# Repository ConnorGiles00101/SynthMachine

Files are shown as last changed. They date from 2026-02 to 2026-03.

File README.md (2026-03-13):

# SynthMachine
A set of Modular synthesizer modules designed around the SSI2130 VCO, SSI2140 Multi-Mode Filter, and the Daisy Seed Microcontroller.

Firmware requires a daisy seed build environment to compile, see daisy seed startup guide (https://daisy.audio/tutorials/cpp-dev-env/), requires updated libdaisy, daisysp, etc... to be cloned from relevant repos.

Very much a prototype.

Credit to timMJN and his Polymorph VCO module: https://github.com/TimMJN/Polymorph-VCO
His designs were helpful reference whilst learning modular synth i/o and standards regarding audio and CV voltage ranges and impedance.

VCO Machine and VCF Machine are designed to use the DAB2130 and DAB2140 breakout boards. As such they have DIP footprints instead of QFN, and do not have decoupling capacitors as they are already included on the breakout.

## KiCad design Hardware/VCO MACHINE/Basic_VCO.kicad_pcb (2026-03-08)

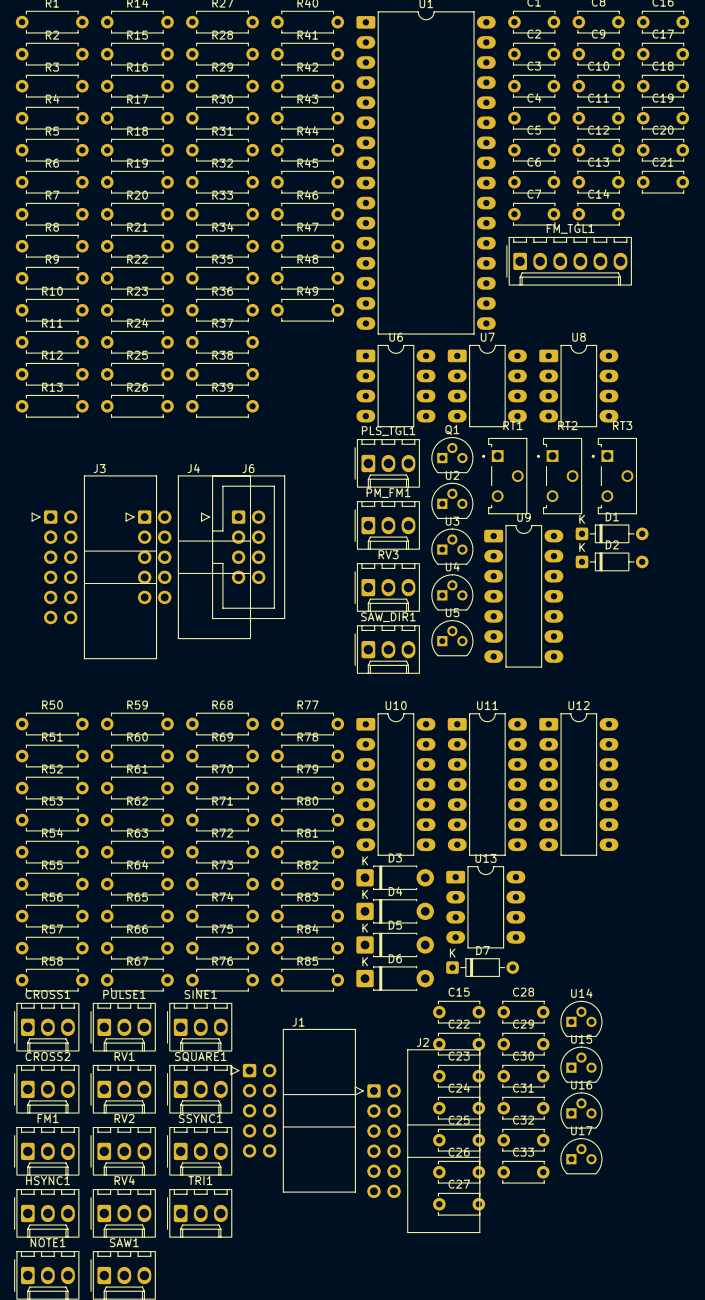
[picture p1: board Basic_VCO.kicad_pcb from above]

Board: 4 copper layers, 170 parts (0 on the bottom side), 105 nets, no tracks yet.

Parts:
C1, C3, C30, C31: 0.33uF; C_Disc_D5.0mm_W2.5mm_P5.00mm
C2, C4, C12, C14, C16, C17, C18, C19, C20, C21, C22, C23, C24, C25, C26, C27, C28, C29, C32, C33: 0.1uF; C_Disc_D5.0mm_W2.5mm_P5.00mm
C5, C6, C8: 10nF; C_Disc_D5.0mm_W2.5mm_P5.00mm
C7: 3.9nF; C_Disc_D5.0mm_W2.5mm_P5.00mm
C9: 10uF; C_Disc_D5.0mm_W2.5mm_P5.00mm
C10, C11, C13, C15: 100pF; C_Disc_D5.0mm_W2.5mm_P5.00mm
CROSS1, CROSS2: AudioJack2_SwitchT; Molex_KK-254_AE-6410-03A_1x03_P2.54mm_Vertical
D1, D2, D7: 1N4148; D_DO-35_SOD27_P7.62mm_Horizontal
D3, D4, D5, D6: 1N5817; D_DO-41_SOD81_P7.62mm_Horizontal
FM1: AudioJack2_SwitchT; Molex_KK-254_AE-6410-03A_1x03_P2.54mm_Vertical
FM_TGL1: SW_DPDT_x2; Molex_KK-254_AE-6410-06A_1x06_P2.54mm_Vertical
HSYNC1: AudioJack2_SwitchT; Molex_KK-254_AE-6410-03A_1x03_P2.54mm_Vertical
J1, J4: Conn_02x05_Odd_Even; IDC-Header_2x05_P2.54mm_Horizontal
J2, J3: Conn_02x06_Odd_Even; IDC-Header_2x06_P2.54mm_Horizontal
J6: Conn_02x05_Odd_Even; IDC-Header_2x04_P2.54mm_Vertical
NOTE1: AudioJack2_SwitchT; Molex_KK-254_AE-6410-03A_1x03_P2.54mm_Vertical
PLS_TGL1: SW_SPDT; Molex_KK-254_AE-6410-03A_1x03_P2.54mm_Vertical
PM_FM1: SW_SPDT; Molex_KK-254_AE-6410-03A_1x03_P2.54mm_Vertical
PULSE1: AudioJack2_SwitchT; Molex_KK-254_AE-6410-03A_1x03_P2.54mm_Vertical
Q1: 2N7000; TO-92
R1, R3, R58, R83: 10; R_Axial_DIN0207_L6.3mm_D2.5mm_P7.62mm_Horizontal
R2, R4, R13, R84, R85: 267; R_Axial_DIN0207_L6.3mm_D2.5mm_P7.62mm_Horizontal
R5: 15k; R_Axial_DIN0207_L6.3mm_D2.5mm_P7.62mm_Horizontal
R6, R7, R10, R15, R26, R35, R37, R45, R47, R57, R59, R63, R67, R71, R75: 10k; R_Axial_DIN0207_L6.3mm_D2.5mm_P7.62mm_Horizontal
R8, R50, R51, R52, R53, R54, R55, R81, R82: 49.9k; R_Axial_DIN0207_L6.3mm_D2.5mm_P7.62mm_Horizontal
R9: 267k; R_Axial_DIN0207_L6.3mm_D2.5mm_P7.62mm_Horizontal
R11, R24, R25, R34: 100k; R_Axial_DIN0207_L6.3mm_D2.5mm_P7.62mm_Horizontal
R12: 22.1k; R_Axial_DIN0207_L6.3mm_D2.5mm_P7.62mm_Horizontal
R14, R16, R33: 100; R_Axial_DIN0207_L6.3mm_D2.5mm_P7.62mm_Horizontal
R17: 19.6k; R_Axial_DIN0207_L6.3mm_D2.5mm_P7.62mm_Horizontal
R18, R20: 4.75k; R_Axial_DIN0207_L6.3mm_D2.5mm_P7.62mm_Horizontal
R19: 4.02k; R_Axial_DIN0207_L6.3mm_D2.5mm_P7.62mm_Horizontal
R21: 12.7k; R_Axial_DIN0207_L6.3mm_D2.5mm_P7.62mm_Horizontal
R22, R23, R27, R28, R29, R30, R31, R32, R38, R39, R40, R41, R42, R43, R44, R46, R48, R49, R60, R64, R68, R72, R76, R78: 20k; R_Axial_DIN0207_L6.3mm_D2.5mm_P7.62mm_Horizontal
R36: 499k; R_Axial_DIN0207_L6.3mm_D2.5mm_P7.62mm_Horizontal
R56: 90.9k; R_Axial_DIN0207_L6.3mm_D2.5mm_P7.62mm_Horizontal
R61, R65, R69, R73: 40.2k; R_Axial_DIN0207_L6.3mm_D2.5mm_P7.62mm_Horizontal
R62, R66, R70, R74, R77, R79: 1k; R_Axial_DIN0207_L6.3mm_D2.5mm_P7.62mm_Horizontal
R80: 1M; R_Axial_DIN0207_L6.3mm_D2.5mm_P7.62mm_Horizontal
RT1, RT2, RT3: 5k; TRIM_PV36Y203C01B00
RV1, RV2, RV4: 100k; Molex_KK-254_AE-6410-03A_1x03_P2.54mm_Vertical
RV3: 5k; Molex_KK-254_AE-6410-03A_1x03_P2.54mm_Vertical
SAW1: AudioJack2_SwitchT; Molex_KK-254_AE-6410-03A_1x03_P2.54mm_Vertical
SAW_DIR1: SW_SPDT; Molex_KK-254_AE-6410-03A_1x03_P2.54mm_Vertical
SINE1: AudioJack2_SwitchT; Molex_KK-254_AE-6410-03A_1x03_P2.54mm_Vertical
SQUARE1: AudioJack2_SwitchT; Molex_KK-254_AE-6410-03A_1x03_P2.54mm_Vertical
SSYNC1: AudioJack2_SwitchT; Molex_KK-254_AE-6410-03A_1x03_P2.54mm_Vertical
TRI1: AudioJack2_SwitchT; Molex_KK-254_AE-6410-03A_1x03_P2.54mm_Vertical
U1: SSI2130; DIP-32_W15.24mm_LongPads
U2, U14: L78L05_TO92; TO-92
U3, U5, U16, U17: TL431LP; TO-92
U4, U15: L79L05_TO92; TO-92
U6, U7, U13: TL072; DIP-8_W7.62mm_LongPads
U8: LM311; DIP-8_W7.62mm_LongPads
U9, U10, U11, U12: TL074; DIP-14_W7.62mm_LongPads

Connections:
+2V5: D3.1 (K), D5.1 (K), FM_TGL1.1 (A), R2.2, R11.2, R12.1, R15.2, R21.2, R28.2, R84.2, RT1.3, U1.23 (VREF), U3.1 (REF), U3.3 (K), U16.1 (REF), U16.3 (K)
+5V: C2.1, C32.1, R2.1, R14.1, R22.2, R35.2, R84.1, RV2.3, SAW_DIR1.1 (A), U1.27 (V+), U2.1 (VO), U14.1 (VO)
+12V: C12.1, C17.1, C18.1, C20.1, C23.1, C24.1, C26.1, C28.1, J1.9, J1.10, J4.9, J4.10, R1.1, R58.1, U6.4 (V-), U7.4 (V-), U8.8 (V+), U9.11 (V-), U10.11 (V-), U11.11 (V-), U12.11 (V-), U13.8 (V+)
-1V0: R40.1, U6.1, U6.2 (-)
-2V5: R4.2, R5.1, R60.1, R64.1, R68.1, R72.1, R85.2, U5.2 (A), U17.2 (A)
-5V: C4.1, C33.1, R4.1, R85.1, U4.3 (VO), U15.3 (VO)
-12V: C14.2, C16.2, C19.2, C21.2, C22.2, C25.2, C27.2, C29.2, J1.1, J1.2, J4.1, J4.2, J6.1, J6.2, R3.1, R17.2, R83.1, U1.8 (V-), U6.8 (V+), U7.8 (V+), U8.4 (V-), U9.4 (V+), U10.4 (V+), U11.4 (V+), U12.4 (V+), U13.4 (V-)
CROSSFADE CV: J3.4, R37.1, R47.1
CROSSFADE IN: J2.4, U11.8, U11.9 (-)
GND: C1.2, C2.2, C3.2, C4.2, C7.2, C8.2, C12.2, C14.1, C16.1, C17.2, C18.2, C19.1, C20.2, C21.1, C22.1, C23.2, C24.2, C25.1, C26.2, C27.1, C28.2, C29.1, C30.2, C31.2, C32.2, C33.2, D4.2 (A), D6.2 (A), J1.3, J1.4, J1.5, J1.6, J1.7, J1.8, J2.2, J3.2, J4.3, J4.4, J4.5, J4.6, J4.7, J4.8, J6.3, J6.4, J6.5, J6.6, J6.7, J6.8, Q1.1 (S), R6.2, R7.1, R16.2, R18.2, R20.2, R23.1, R24.1, R25.1, R26.2, R33.1, R48.1, R51.2, R54.1, R57.1, R80.2, R82.2, RT1.1, RT2.1, RV1.1, RV2.1, RV4.1, SAW_DIR1.3 (C), U1.15 (DGND), U1.16 (AGND), U1.20 (HFT_BASE), U2.2 (GND), U3.2 (A), U4.1 (GND), U5.1 (REF), U5.3 (K), U6.5 (+), U7.3 (+), U8.1 (GND), U9.3 (+), U9.5 (+), U9.12 (+), U11.12 (+), U12.3 (+), U12.5 (+), U12.10 (+), U12.12 (+), U13.2 (-), U14.2 (GND), U15.1 (GND), U16.2 (A), U17.1 (REF), U17.3 (K)
HARD SYNC CV: C5.1, J3.6, R7.2
HARD SYNC IN: J2.6, U10.13 (-), U10.14
LIN FREQ IN: R36.2, U1.21 (LIN_FREQ)
MIX OUT: R26.1, U1.25 (MIX_OUT)
NOTE CV: J3.12, R8.1
NOTE IN: J2.12, U10.1, U10.2 (-)
unnamed: C8.1, R13.1
unnamed: C13.1, R34.2
unnamed: C15.2, R78.2, R79.1, U13.7
unnamed: D1.2 (A), D2.1 (K), U9.1
unnamed: D1.1 (K), R38.2, R39.1
unnamed: D2.2 (A), R41.2, R42.1
unnamed: D3.2 (A), D4.1 (K), R81.2, R82.1, U10.10 (+)
unnamed: D5.2 (A), D6.1 (K), R50.2, R51.1, U10.12 (+)
unnamed: D7.2 (A), U11.7
unnamed: D7.1 (K), RV4.3, U11.6 (-)
unnamed: FM_TGL1.2 (B), R36.1
unnamed: C11.2, FM_TGL1.3 (C), R32.2, U7.7
unnamed: FM_TGL1.4 (A), SAW_DIR1.2 (B)
unnamed: C13.2, FM_TGL1.6 (C), Q1.2 (G), R35.1, U8.7
unnamed: C9.2, PM_FM1.1 (A), R27.1
unnamed: C9.1, PM_FM1.3 (C)
unnamed: Q1.3 (D), R31.2, U7.5 (+)
unnamed: R9.1, RT2.2
unnamed: R10.1, RT1.2
unnamed: R12.2, RT3.2, RT3.3
unnamed: R14.2, R15.1, RV3.3
unnamed: R16.1, R17.1, RV3.1
unnamed: R43.2, R44.2, R45.2, U9.7
unnamed: R46.2, R49.1, U9.8
unnamed: R53.1, RV2.2
unnamed: R55.2, R56.1, U11.1
unnamed: R61.1, R62.2, U12.1
unnamed: R65.1, R66.2, U12.7
unnamed: R69.1, R70.2, U12.8
unnamed: R73.1, R74.2, U12.14
unnamed: R76.1, R77.2, U13.1
unnamed: R13.2, U1.26 (BW_COMP)
unnamed: R8.2, R9.2, R10.2, R11.1, U1.7 (EXPO_FREQ)
unnamed: RT3.1, U1.22 (EXPO_SCALE)
unnamed: C5.2, U1.17 (HARD_SYNC)
unnamed: RT2.3, U1.6 (HF_TRACK)
unnamed: C6.2, U1.19 (SOFT_SYNC)
unnamed: C7.1, U1.14 (TCAP)
unnamed: R18.1, R19.1, U1.2 (SINE_IN+)
unnamed: R20.1, R21.1, U1.3 (SINE_IN-)
unnamed: R24.2, U1.12 (AUX1_MIX)
unnamed: R25.2, U1.13 (AUX2_MIX)
unnamed: C1.1, R1.2, U2.3 (VI)
unnamed: C3.1, R3.2, U4.2 (VI)
unnamed: R5.2, R6.1, U6.3 (+)
unnamed: U6.6 (-), U6.7
unnamed: C10.1, R27.2, R28.1, R29.1, U7.2 (-)
unnamed: C11.1, R30.2, R32.1, U7.6 (-)
unnamed: R33.2, R34.1, U8.2 (+)
unnamed: C10.2, R29.2, R30.1, R31.1, U7.1, U8.3 (-)
unnamed: R37.2, R38.1, R40.2, R41.1, U9.2 (-)
unnamed: R42.2, R43.1, U9.6 (-)
unnamed: R47.2, R48.2, U9.10 (+)
unnamed: R45.1, R46.1, U9.9 (-)
unnamed: U9.13 (-), U9.14
unnamed: R80.1, U10.3 (+)
unnamed: RV1.2, U10.5 (+)
unnamed: R52.2, R53.2, U11.3 (+)
unnamed: R54.2, R55.1, U11.2 (-)
unnamed: R56.2, R57.2, U11.5 (+)
unnamed: RV4.2, U11.10 (+)
unnamed: U11.13 (-), U11.14
unnamed: R59.2, R60.2, R61.2, U12.2 (-)
unnamed: R63.2, R64.2, R65.2, U12.6 (-)
unnamed: R67.2, R68.2, R69.2, U12.9 (-)
unnamed: R71.2, R72.2, R73.2, U12.13 (-)
unnamed: R75.2, R76.2, U13.3 (+)
unnamed: C15.1, R78.1, U13.5 (+)
unnamed: C30.1, R58.2, U14.3 (VI)
unnamed: C31.1, R83.2, U15.2 (VI)
PM/FM CV: J3.10, PM_FM1.2 (B)
PM/FM IN: J2.10, U10.6 (-), U10.7
PULSE MIX: R44.1, U1.11 (PULSE_MIX)
PULSE OUT: J3.3, J3.7, U1.30 (PULSE_OUT)
PULSE WAVE: J2.3, J2.7, R71.1
PWM+: RV3.2, U1.32 (PWM+)
PWM-: PLS_TGL1.2 (B), U1.31 (PWM-)
SAW MIX: R49.2, U1.10 (SAW_MIX)
SAW OUT: J3.9, PLS_TGL1.3 (C), U1.29 (SAW_OUT)
SAW WAVE: J2.9, R63.1
SINE OUT: J3.1, U1.24 (SINE_OUT)
SINE WAVE: J2.1, R75.1
SOFT SYNC CV: C6.1, J3.8
SOFT SYNC IN: J2.8, U10.8, U10.9 (-)
SQUARE OUT: J3.5, R22.1, R23.2, U1.28 (SQUARE_OUT)
SQUARE WAVE: J2.5, R67.1
TIME REV IN: FM_TGL1.5 (B), U1.18 (TIME_REVERSE)
TRI MIX: R39.2, U1.9 (TRI_MIX)
TRI OUT: PLS_TGL1.1 (A), R19.2, U1.1 (TRI_OUT)

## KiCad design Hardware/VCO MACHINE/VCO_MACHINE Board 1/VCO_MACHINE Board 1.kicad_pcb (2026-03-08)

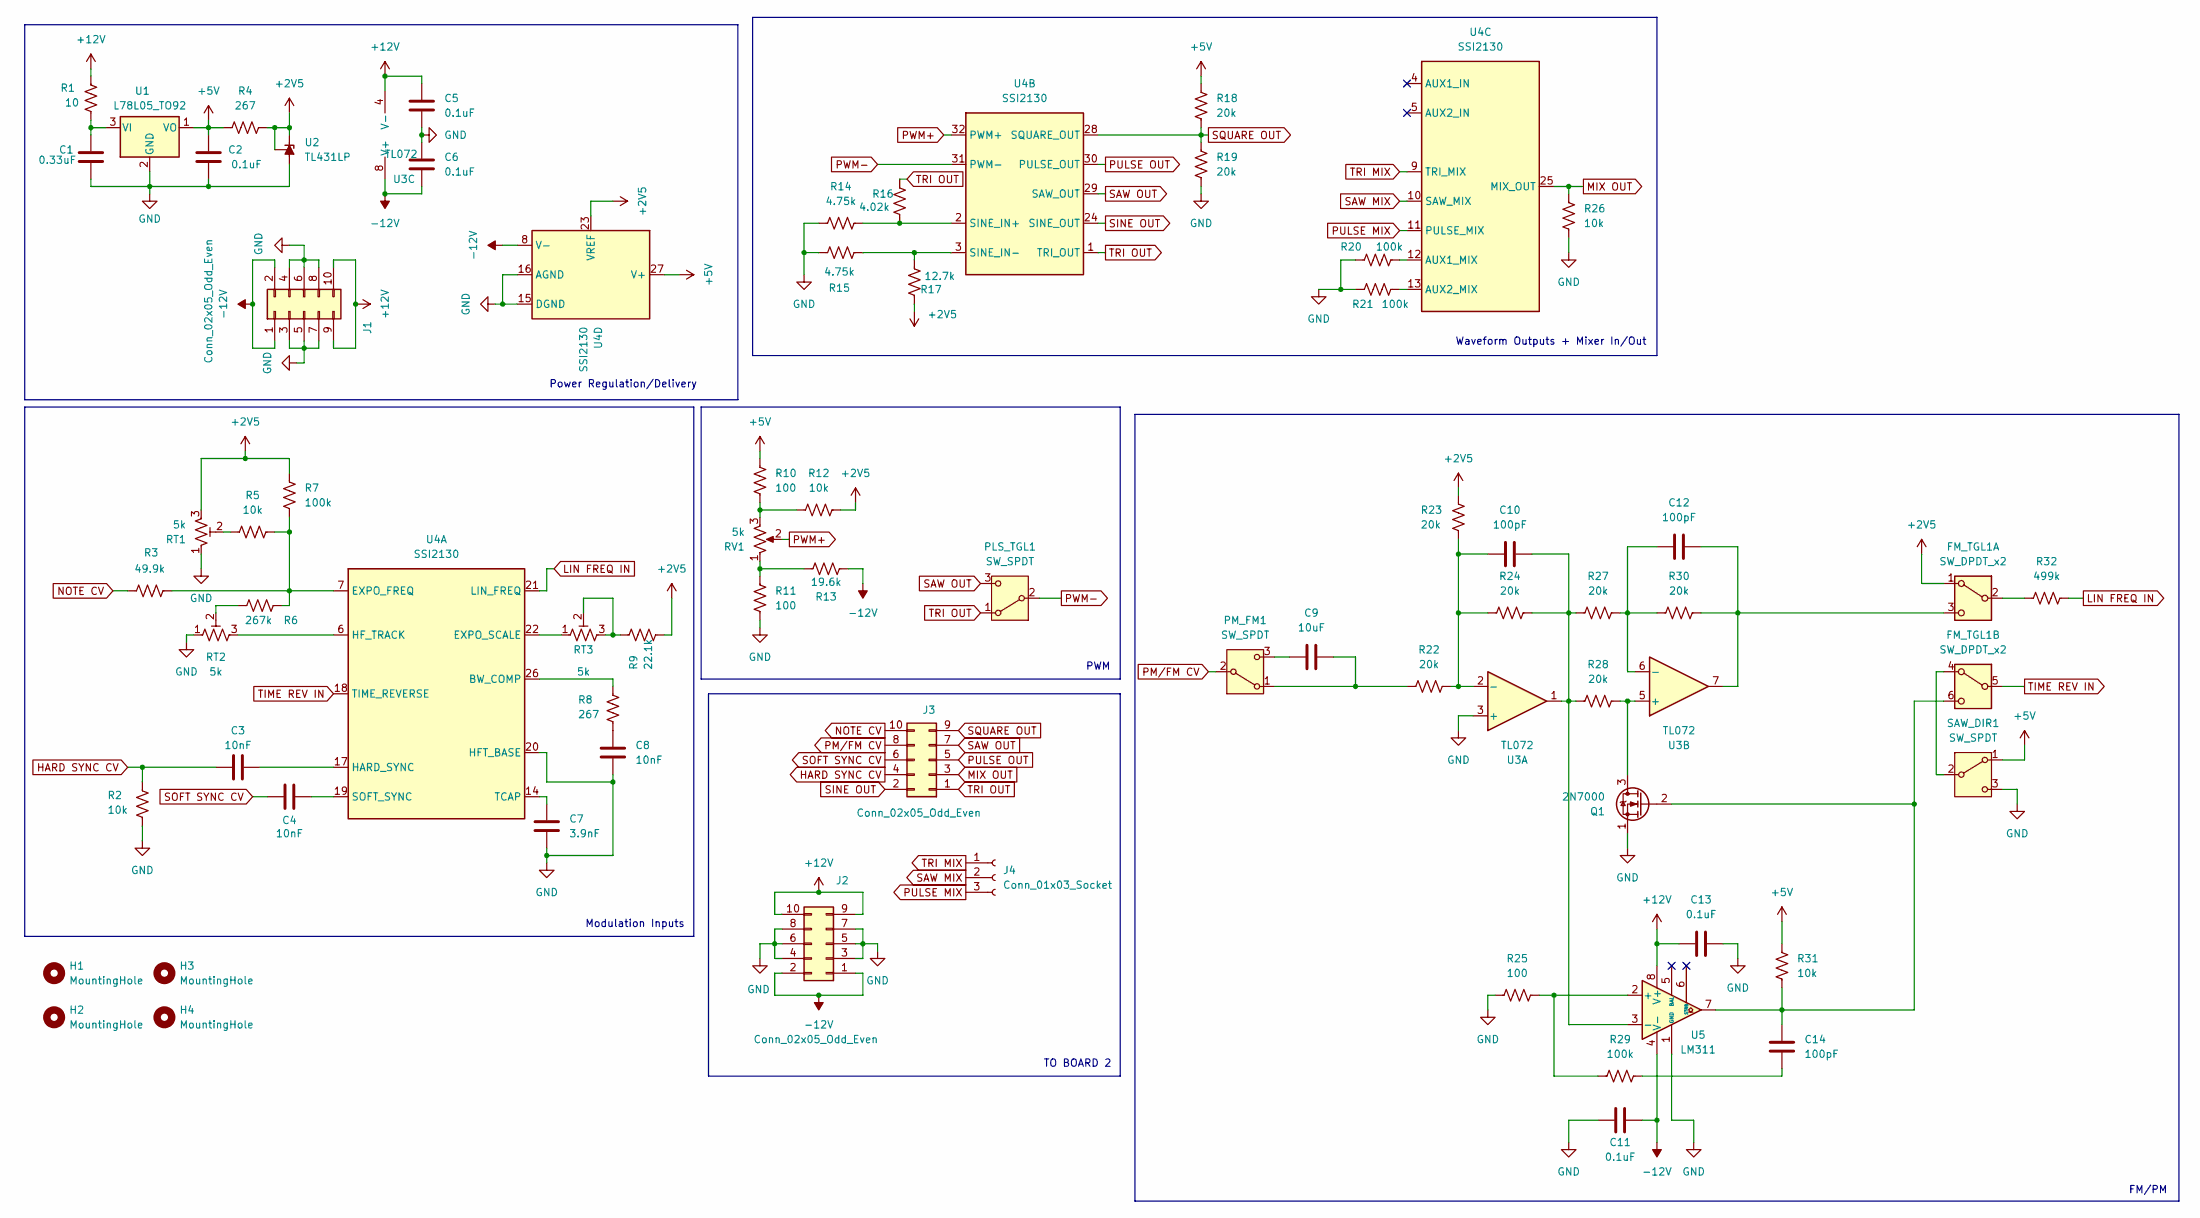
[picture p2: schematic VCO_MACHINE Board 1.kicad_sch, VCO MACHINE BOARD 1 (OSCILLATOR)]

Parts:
C1: 0.33uF; C_Disc_D5.0mm_W2.5mm_P5.00mm; LCSC C73142
C2, C5, C6, C11, C13: 0.1uF; C_Disc_D5.0mm_W2.5mm_P5.00mm; LCSC C307331
C3, C4, C8: 10nF; C_Disc_D5.0mm_W2.5mm_P5.00mm; LCSC C60133
C7: 3.9nF; C_Disc_D5.0mm_W2.5mm_P5.00mm; LCSC C326569
C9: 10uF; C_Disc_D5.0mm_W2.5mm_P5.00mm; LCSC C2932476
C10, C12, C14: 100pF; C_Disc_D5.0mm_W2.5mm_P5.00mm; LCSC C106200
FM_TGL1: SW_DPDT_x2; Molex_KK-254_1x06_P2.54mm_Horizontal
H1, H2, H3, H4: MountingHole; MountingHole_2.2mm_M2
J1: Conn_02x05_Odd_Even; IDC-Header_2x05_P2.54mm_Vertical
J2: Conn_02x05_Odd_Even; IDC-Header_2x06_P2.54mm_Horizontal
J3: Conn_02x05_Odd_Even; IDC-Header_2x05_P2.54mm_Horizontal
J4: Conn_01x03_Socket; Molex_KK-254_1x03_P2.54mm_Horizontal
PLS_TGL1: SW_SPDT; Molex_KK-254_1x03_P2.54mm_Horizontal
PM_FM1: SW_SPDT; Molex_KK-254_1x03_P2.54mm_Horizontal
Q1: 2N7000; TO-92; LCSC C8545
R1: 10; R_Axial_DIN0207_L6.3mm_D2.5mm_P7.62mm_Horizontal; LCSC C17903
R2, R5, R12, R26, R31: 10k; R_Axial_DIN0207_L6.3mm_D2.5mm_P7.62mm_Horizontal; LCSC C25744
R3: 49.9k; R_Axial_DIN0207_L6.3mm_D2.5mm_P7.62mm_Horizontal; LCSC C853300
R4, R8: 267; R_Axial_DIN0207_L6.3mm_D2.5mm_P7.62mm_Horizontal; LCSC C2974054
R6: 267k; R_Axial_DIN0207_L6.3mm_D2.5mm_P7.62mm_Horizontal; LCSC C4315442
R7, R20, R21, R29: 100k; R_Axial_DIN0207_L6.3mm_D2.5mm_P7.62mm_Horizontal; LCSC C852472
R9: 22.1k; R_Axial_DIN0207_L6.3mm_D2.5mm_P7.62mm_Horizontal; LCSC C852648
R10, R11, R25: 100; R_Axial_DIN0207_L6.3mm_D2.5mm_P7.62mm_Horizontal; LCSC C705627
R13: 19.6k; R_Axial_DIN0207_L6.3mm_D2.5mm_P7.62mm_Horizontal; LCSC C850848
R14, R15: 4.75k; R_Axial_DIN0207_L6.3mm_D2.5mm_P7.62mm_Horizontal; LCSC C854352
R16: 4.02k; R_Axial_DIN0207_L6.3mm_D2.5mm_P7.62mm_Horizontal; LCSC C852810
R17: 12.7k; R_Axial_DIN0207_L6.3mm_D2.5mm_P7.62mm_Horizontal; LCSC C852509
R18, R19, R22, R23, R24, R27, R28, R30: 20k; R_Axial_DIN0207_L6.3mm_D2.5mm_P7.62mm_Horizontal; LCSC C705630
R32: 499k; R_Axial_DIN0207_L6.3mm_D2.5mm_P7.62mm_Horizontal; LCSC C2074186
RT1, RT2, RT3: 5k; TRIM_PV36Y203C01B00
RV1: 5k; Molex_KK-254_1x03_P2.54mm_Horizontal
SAW_DIR1: SW_SPDT; Molex_KK-254_1x03_P2.54mm_Horizontal
U1: L78L05_TO92; TO-92; LCSC C42738
U2: TL431LP; TO-92; LCSC C18814
U3: TL072; DIP-8_W7.62mm_LongPads; LCSC C6962
U4: SSI2130; DIP-32_W15.24mm
U5: LM311; DIP-8_W7.62mm_LongPads; LCSC C12597

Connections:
+2V5: FM_TGL1.1 (A), R4.2, R7.2, R9.1, R12.2, R17.2, R23.2, RT1.3, U2.1 (REF), U2.3 (K), U4.23 (VREF)
+5V: C2.1, R4.1, R10.1, R18.2, R31.2, SAW_DIR1.1 (A), U1.1 (VO), U4.27 (V+)
+12V: C5.1, C13.1, J1.9, J1.10, J2.9, J2.10, R1.1, U3.4 (V-), U5.8 (V+)
-12V: C6.2, C11.2, J1.1, J1.2, J2.1, J2.2, R13.2, U3.8 (V+), U4.8 (V-), U5.4 (V-)
GND: C1.2, C2.2, C5.2, C6.1, C7.2, C8.2, C11.1, C13.2, J1.3, J1.4, J1.5, J1.6, J1.7, J1.8, J2.3, J2.4, J2.5, J2.6, J2.7, J2.8, Q1.1 (S), R2.1, R11.2, R14.2, R15.2, R19.1, R20.1, R21.1, R25.1, R26.2, RT1.1, RT2.1, SAW_DIR1.3 (C), U1.2 (GND), U2.2 (A), U3.3 (+), U4.15 (DGND), U4.16 (AGND), U4.20 (HFT_BASE), U5.1 (GND)
HARD SYNC CV: C3.1, J3.4, R2.2
LIN FREQ IN: R32.2, U4.21 (LIN_FREQ)
MIX OUT: J3.3, R26.1, U4.25 (MIX_OUT)
NOTE CV: J3.10, R3.1
unnamed: C8.1, R8.1
unnamed: C14.1, R29.2
unnamed: FM_TGL1.2 (B), R32.1
unnamed: C12.2, FM_TGL1.3 (C), R30.2, U3.7
unnamed: FM_TGL1.4 (A), SAW_DIR1.2 (B)
unnamed: C14.2, FM_TGL1.6 (C), Q1.2 (G), R31.1, U5.7
unnamed: C9.2, PM_FM1.1 (A), R22.1
unnamed: C9.1, PM_FM1.3 (C)
unnamed: Q1.3 (D), R28.2, U3.5 (+)
unnamed: R5.1, RT1.2
unnamed: R6.1, RT2.2
unnamed: R9.2, RT3.2, RT3.3
unnamed: R10.2, R12.1, RV1.3
unnamed: R11.1, R13.1, RV1.1
unnamed: C1.1, R1.2, U1.3 (VI)
unnamed: C10.1, R22.2, R23.1, R24.1, U3.2 (-)
unnamed: C12.1, R27.2, R30.1, U3.6 (-)
unnamed: R8.2, U4.26 (BW_COMP)
unnamed: R3.2, R5.2, R6.2, R7.1, U4.7 (EXPO_FREQ)
unnamed: RT3.1, U4.22 (EXPO_SCALE)
unnamed: C3.2, U4.17 (HARD_SYNC)
unnamed: RT2.3, U4.6 (HF_TRACK)
unnamed: C4.2, U4.19 (SOFT_SYNC)
unnamed: C7.1, U4.14 (TCAP)
unnamed: R14.1, R16.1, U4.2 (SINE_IN+)
unnamed: R15.1, R17.1, U4.3 (SINE_IN-)
unnamed: R20.2, U4.12 (AUX1_MIX)
unnamed: R21.2, U4.13 (AUX2_MIX)
unnamed: R25.2, R29.1, U5.2 (+)
unnamed: C10.2, R24.2, R27.1, R28.1, U3.1, U5.3 (-)
PM/FM CV: J3.8, PM_FM1.2 (B)
PULSE MIX: J4.3, U4.11 (PULSE_MIX)
PULSE OUT: J3.5, U4.30 (PULSE_OUT)
PWM+: RV1.2, U4.32 (PWM+)
PWM-: PLS_TGL1.2 (B), U4.31 (PWM-)
SAW MIX: J4.2, U4.10 (SAW_MIX)
SAW OUT: J3.7, PLS_TGL1.3 (C), U4.29 (SAW_OUT)
SINE OUT: J3.2, U4.24 (SINE_OUT)
SOFT SYNC CV: C4.1, J3.6
SQUARE OUT: J3.9, R18.1, R19.2, U4.28 (SQUARE_OUT)
TIME REV IN: FM_TGL1.5 (B), U4.18 (TIME_REVERSE)
TRI MIX: J4.1, U4.9 (TRI_MIX)
TRI OUT: J3.1, PLS_TGL1.1 (A), R16.2, U4.1 (TRI_OUT)

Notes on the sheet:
Waveform Outputs + Mixer In/Out
FM/PM
Modulation Inputs
TO BOARD 2
PWM
Power Regulation/Delivery

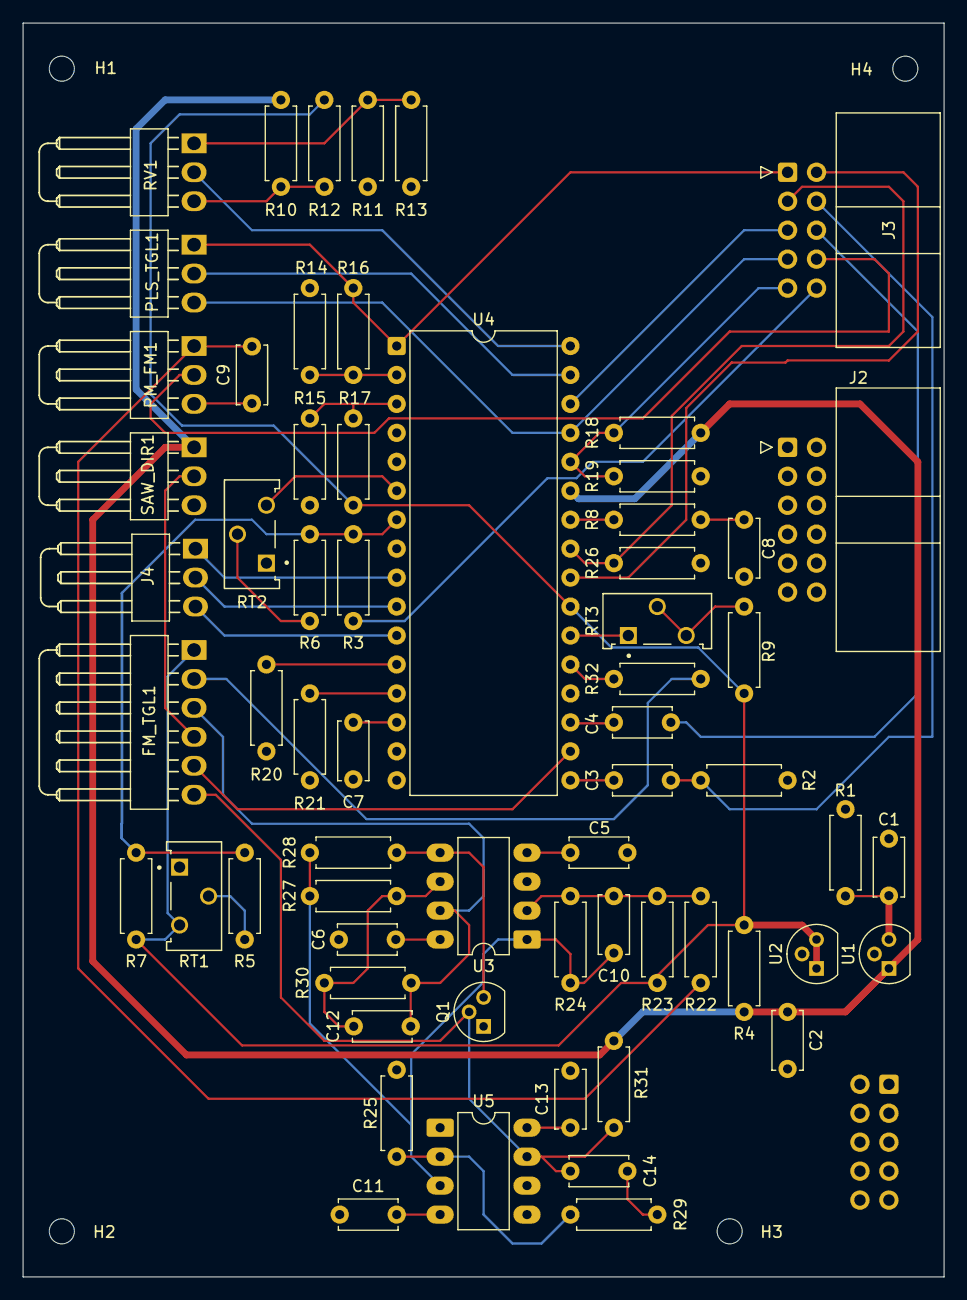
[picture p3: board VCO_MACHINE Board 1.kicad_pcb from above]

Board: 4 copper layers, 80.8 x 110.0 mm, 68 parts (1 on the bottom side), 52 nets.

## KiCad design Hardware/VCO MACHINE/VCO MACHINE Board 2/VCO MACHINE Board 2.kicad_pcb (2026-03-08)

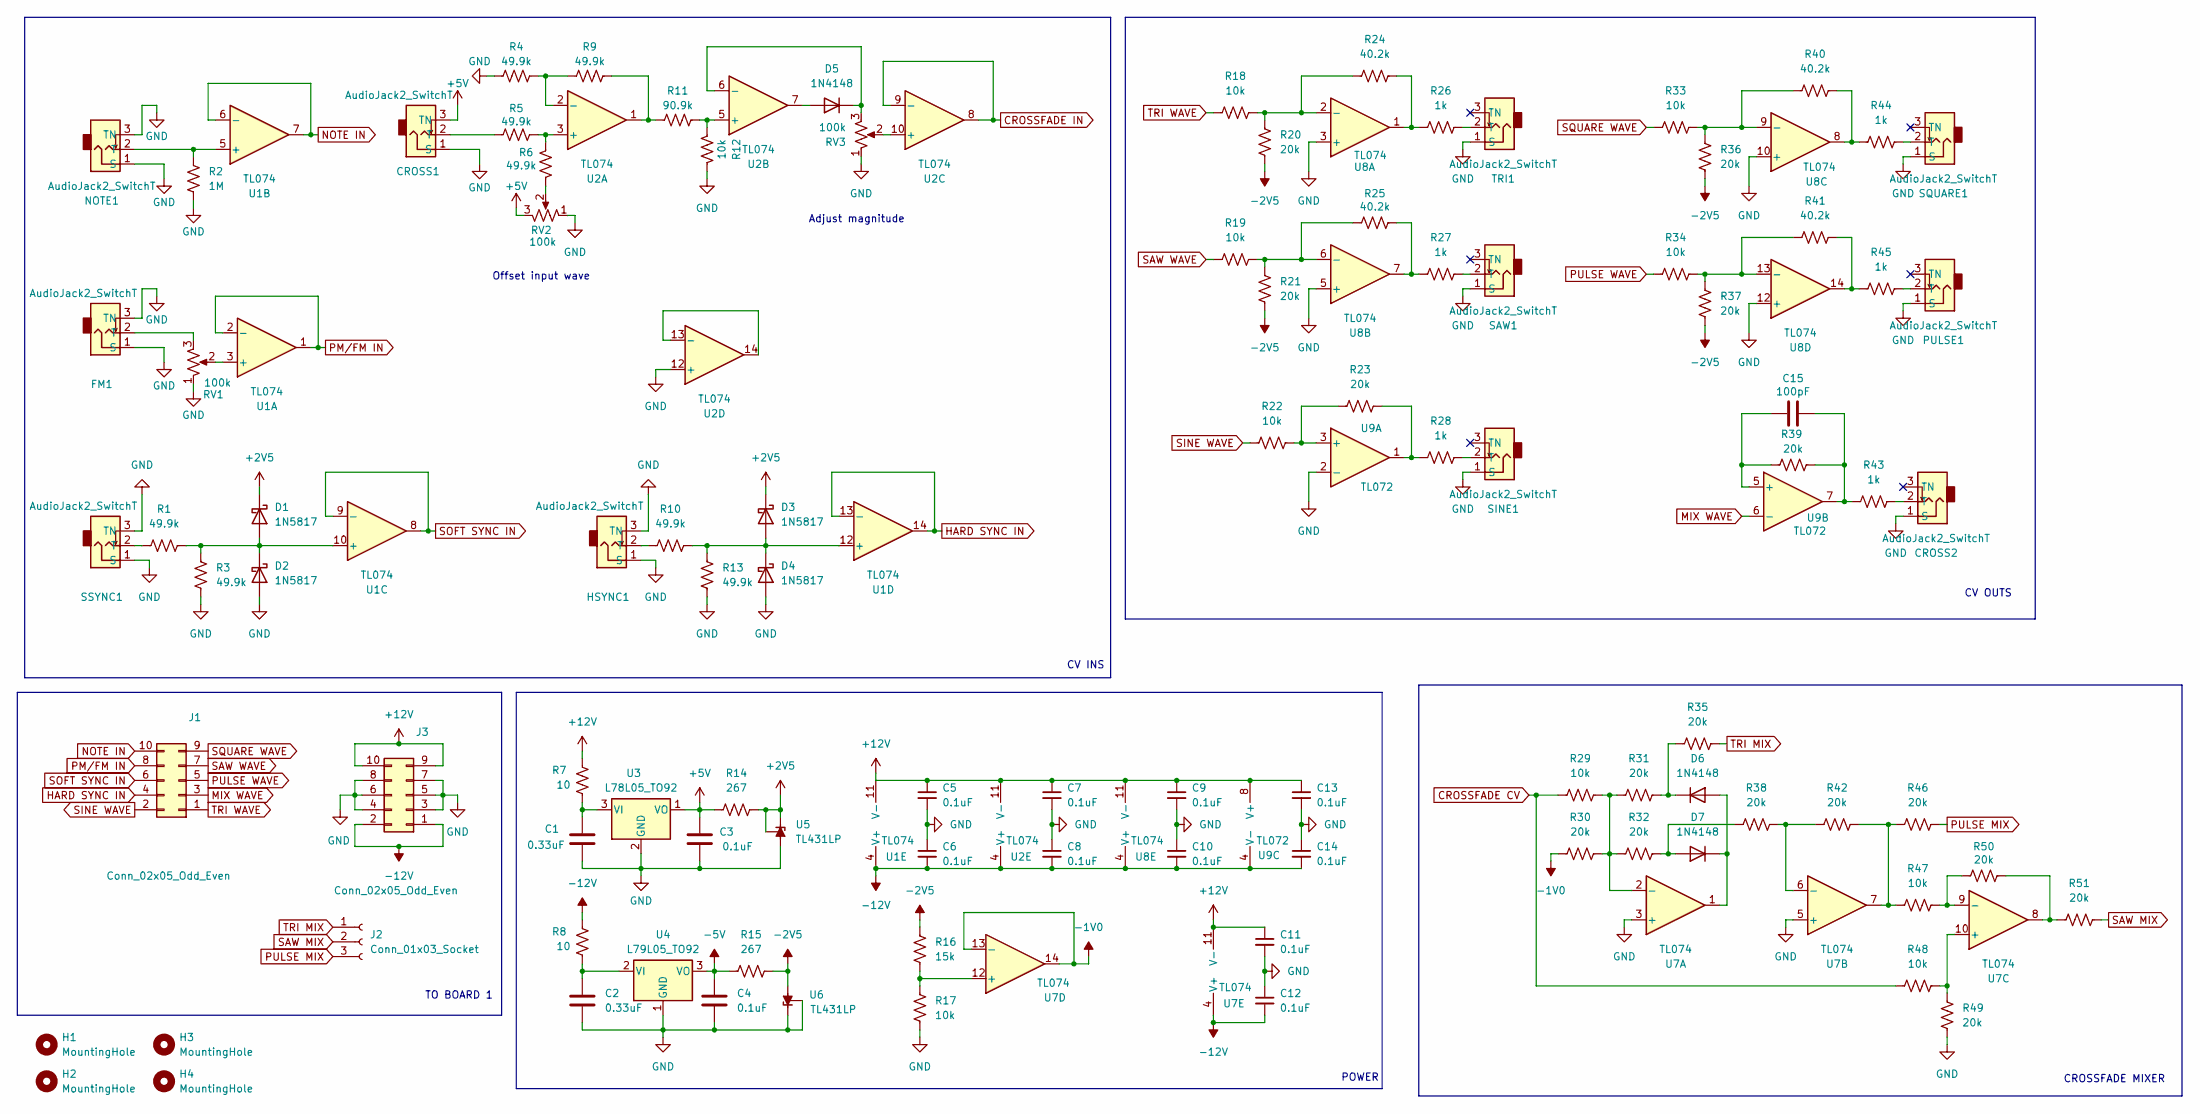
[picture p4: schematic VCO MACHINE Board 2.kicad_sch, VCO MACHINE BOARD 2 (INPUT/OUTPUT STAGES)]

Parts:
C1, C2: 0.33uF; C_Disc_D5.0mm_W2.5mm_P5.00mm; LCSC C73142
C3, C4: 0.1uF; C_Disc_D5.0mm_W2.5mm_P5.00mm; LCSC C307331
C5, C6, C7, C8, C9, C10, C11, C12, C13, C14: 0.1uF; C_Disc_D5.0mm_W2.5mm_P5.00mm
C15: 100pF; C_Disc_D5.0mm_W2.5mm_P5.00mm; LCSC C106200
CROSS1, CROSS2: AudioJack2_SwitchT; Molex_KK-254_1x03_P2.54mm_Horizontal
D1, D2, D3, D4: 1N5817; D_DO-41_SOD81_P7.62mm_Horizontal; LCSC C727113
D5, D6, D7: 1N4148; D_DO-35_SOD27_P7.62mm_Horizontal; LCSC C81598
FM1: AudioJack2_SwitchT; Molex_KK-254_1x03_P2.54mm_Horizontal
H1, H2, H3, H4: MountingHole; MountingHole_2.2mm_M2
HSYNC1: AudioJack2_SwitchT; Molex_KK-254_1x03_P2.54mm_Horizontal
J1: Conn_02x05_Odd_Even; IDC-Header_2x05_P2.54mm_Horizontal
J2: Conn_01x03_Socket; IDC-Header_2x05_P2.54mm_Horizontal
J3: Conn_02x05_Odd_Even; Molex_KK-254_1x03_P2.54mm_Horizontal
NOTE1: AudioJack2_SwitchT; Molex_KK-254_1x03_P2.54mm_Horizontal
PULSE1: AudioJack2_SwitchT; Molex_KK-254_1x03_P2.54mm_Horizontal
R1, R3, R4, R5, R6, R9, R10, R13: 49.9k; R_Axial_DIN0207_L6.3mm_D2.5mm_P7.62mm_Horizontal; LCSC C853300
R2: 1M; R_Axial_DIN0207_L6.3mm_D2.5mm_P7.62mm_Horizontal; LCSC C1884615
R7, R8: 10; R_Axial_DIN0207_L6.3mm_D2.5mm_P7.62mm_Horizontal; LCSC C17903
R11: 90.9k; R_Axial_DIN0207_L6.3mm_D2.5mm_P7.62mm_Horizontal; LCSC C854454
R12, R17, R18, R19, R22, R29, R33, R34, R47, R48: 10k; R_Axial_DIN0207_L6.3mm_D2.5mm_P7.62mm_Horizontal; LCSC C25744
R14, R15: 267; R_Axial_DIN0207_L6.3mm_D2.5mm_P7.62mm_Horizontal; LCSC C2974054
R16: 15k; R_Axial_DIN0207_L6.3mm_D2.5mm_P7.62mm_Horizontal; LCSC C25756
R20, R21, R23, R30, R31, R32, R35, R36, R37, R38, R39, R42, R46, R49, R50, R51: 20k; R_Axial_DIN0207_L6.3mm_D2.5mm_P7.62mm_Horizontal; LCSC C705630
R24, R25, R40, R41: 40.2k; R_Axial_DIN0207_L6.3mm_D2.5mm_P7.62mm_Horizontal; LCSC C852775
R26, R27, R28, R43, R44, R45: 1k; R_Axial_DIN0207_L6.3mm_D2.5mm_P7.62mm_Horizontal; LCSC C706405
RV1, RV2, RV3: 100k; Molex_KK-254_1x03_P2.54mm_Horizontal
SAW1: AudioJack2_SwitchT; Molex_KK-254_1x03_P2.54mm_Horizontal
SINE1: AudioJack2_SwitchT; Molex_KK-254_1x03_P2.54mm_Horizontal
SQUARE1: AudioJack2_SwitchT; Molex_KK-254_1x03_P2.54mm_Horizontal
SSYNC1: AudioJack2_SwitchT; Molex_KK-254_1x03_P2.54mm_Horizontal
TRI1: AudioJack2_SwitchT; Molex_KK-254_1x03_P2.54mm_Horizontal
U1, U2, U7, U8: TL074; DIP-14_W7.62mm_LongPads; LCSC C6964
U3: L78L05_TO92; TO-92; LCSC C42738
U4: L79L05_TO92; TO-92
U5, U6: TL431LP; TO-92; LCSC C18814
U9: TL072; DIP-8_W7.62mm_LongPads; LCSC C6962

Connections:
+2V5: D1.1 (K), D3.1 (K), R14.2, U5.1 (REF), U5.3 (K)
+5V: C3.1, CROSS1.3 (TN), R14.1, RV2.3, U3.1 (VO)
+12V: C5.1, C7.1, C9.1, C11.1, C13.1, J3.9, J3.10, R7.1, U1.11 (V-), U2.11 (V-), U7.11 (V-), U8.11 (V-), U9.8 (V+)
-1V0: R30.1, U7.13 (-), U7.14
-2V5: R15.2, R16.1, R20.1, R21.1, R36.1, R37.1, U6.2 (A)
-5V: C4.1, R15.1, U4.3 (VO)
-12V: C6.2, C8.2, C10.2, C12.2, C14.2, J3.1, J3.2, R8.1, U1.4 (V+), U2.4 (V+), U7.4 (V+), U8.4 (V+), U9.4 (V-)
CROSSFADE CV: R29.1, R48.1
CROSSFADE IN: U2.8, U2.9 (-)
GND: C1.2, C2.2, C3.2, C4.2, C5.2, C6.1, C7.2, C8.1, C9.2, C10.1, C11.2, C12.1, C13.2, C14.1, CROSS1.1 (S), CROSS2.1 (S), D2.2 (A), D4.2 (A), FM1.1 (S), FM1.3 (TN), HSYNC1.1 (S), HSYNC1.3 (TN), J3.3, J3.4, J3.5, J3.6, J3.7, J3.8, NOTE1.1 (S), NOTE1.3 (TN), PULSE1.1 (S), R2.2, R3.2, R4.1, R12.1, R13.2, R17.2, R49.1, RV1.1, RV2.1, RV3.1, SAW1.1 (S), SINE1.1 (S), SQUARE1.1 (S), SSYNC1.1 (S), SSYNC1.3 (TN), TRI1.1 (S), U2.12 (+), U3.2 (GND), U4.1 (GND), U5.2 (A), U6.1 (REF), U6.3 (K), U7.3 (+), U7.5 (+), U8.3 (+), U8.5 (+), U8.10 (+), U8.12 (+), U9.2 (-)
HARD SYNC IN: J1.4, U1.13 (-), U1.14
MIX WAVE: J1.3, U9.6 (-)
NOTE IN: J1.10, U1.6 (-), U1.7
unnamed: C15.2, R39.2, R43.1, U9.7
unnamed: CROSS1.2 (T), R5.1
unnamed: CROSS2.2 (T), R43.2
unnamed: D1.2 (A), D2.1 (K), R1.2, R3.1, U1.10 (+)
unnamed: D3.2 (A), D4.1 (K), R10.2, R13.1, U1.12 (+)
unnamed: D5.2 (A), U2.7
unnamed: D5.1 (K), RV3.3, U2.6 (-)
unnamed: D6.2 (A), D7.1 (K), U7.1
unnamed: D6.1 (K), R31.2, R35.1
unnamed: D7.2 (A), R32.2, R38.1
unnamed: FM1.2 (T), RV1.3
unnamed: HSYNC1.2 (T), R10.1
unnamed: NOTE1.2 (T), R2.1, U1.5 (+)
unnamed: PULSE1.2 (T), R45.1
unnamed: R6.1, RV2.2
unnamed: R9.2, R11.1, U2.1
unnamed: R23.1, R28.2, U9.1
unnamed: R24.1, R26.2, U8.1
unnamed: R25.1, R27.2, U8.7
unnamed: R40.1, R44.2, U8.8
unnamed: R41.1, R45.2, U8.14
unnamed: R42.2, R46.2, R47.2, U7.7
unnamed: R50.2, R51.1, U7.8
unnamed: R27.1, SAW1.2 (T)
unnamed: R28.1, SINE1.2 (T)
unnamed: R44.1, SQUARE1.2 (T)
unnamed: R1.1, SSYNC1.2 (T)
unnamed: R26.1, TRI1.2 (T)
unnamed: RV1.2, U1.3 (+)
unnamed: R5.2, R6.2, U2.3 (+)
unnamed: R4.2, R9.1, U2.2 (-)
unnamed: R11.2, R12.2, U2.5 (+)
unnamed: RV3.2, U2.10 (+)
unnamed: U2.13 (-), U2.14
unnamed: C1.1, R7.2, U3.3 (VI)
unnamed: C2.1, R8.2, U4.2 (VI)
unnamed: R29.2, R30.2, R31.1, R32.1, U7.2 (-)
unnamed: R38.2, R42.1, U7.6 (-)
unnamed: R48.2, R49.2, U7.10 (+)
unnamed: R47.1, R50.1, U7.9 (-)
unnamed: R16.2, R17.1, U7.12 (+)
unnamed: R18.2, R20.2, R24.2, U8.2 (-)
unnamed: R19.2, R21.2, R25.2, U8.6 (-)
unnamed: R33.2, R36.2, R40.2, U8.9 (-)
unnamed: R34.2, R37.2, R41.2, U8.13 (-)
unnamed: R22.2, R23.2, U9.3 (+)
unnamed: C15.1, R39.1, U9.5 (+)
PM/FM IN: J1.8, U1.1, U1.2 (-)
PULSE MIX: J2.3, R46.1
PULSE WAVE: J1.5, R34.1
SAW MIX: J2.2, R51.2
SAW WAVE: J1.7, R19.1
SINE WAVE: J1.2, R22.1
SOFT SYNC IN: J1.6, U1.8, U1.9 (-)
SQUARE WAVE: J1.9, R33.1
TRI MIX: J2.1, R35.2
TRI WAVE: J1.1, R18.1

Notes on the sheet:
CV INS
CROSSFADE MIXER
Offset input wave
Adjust magnitude
TO BOARD 1
POWER
CV OUTS

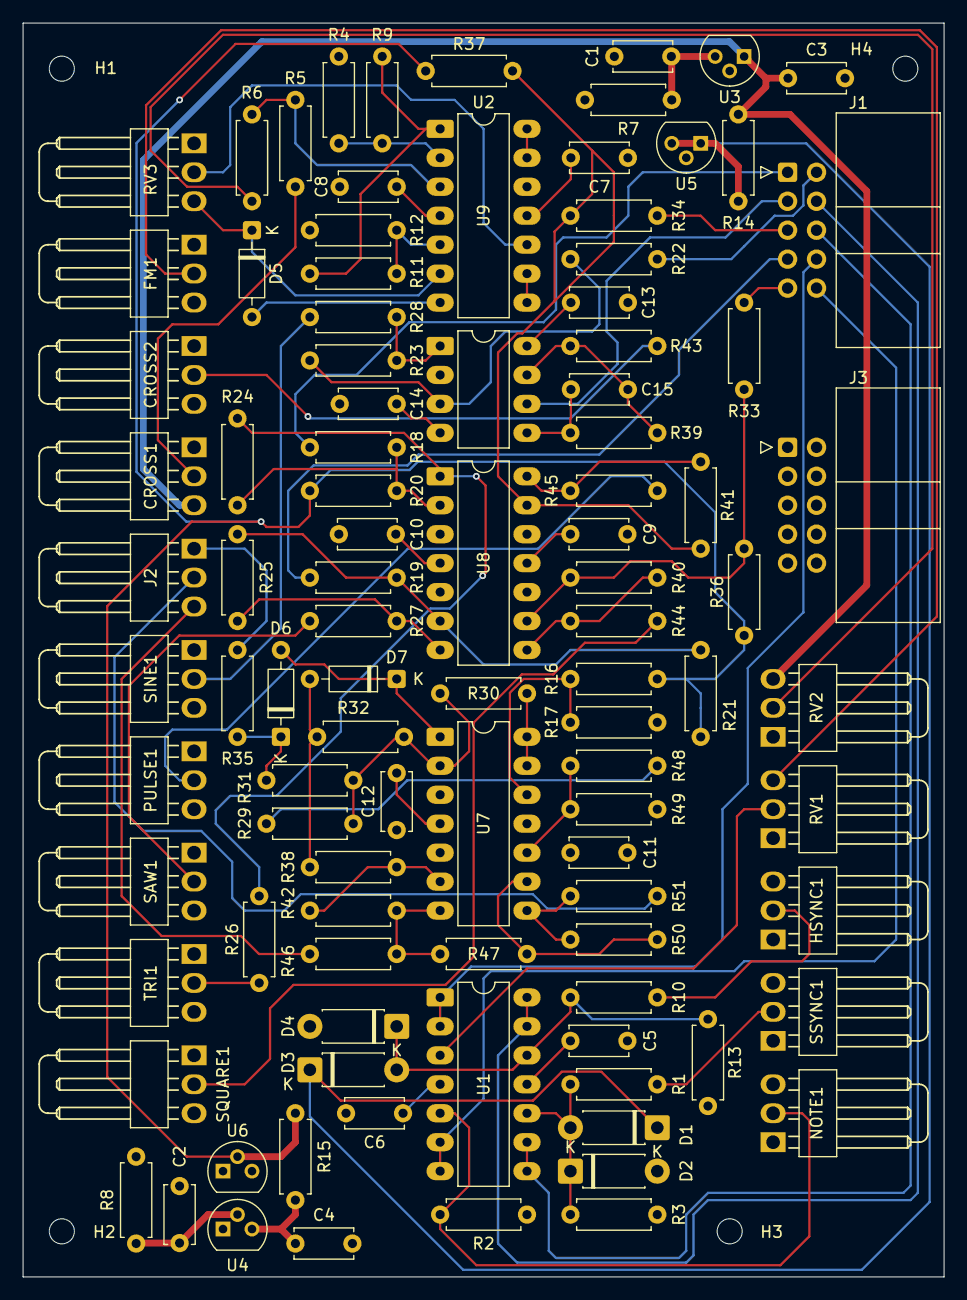
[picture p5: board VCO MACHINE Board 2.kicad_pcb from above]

Board: 4 copper layers, 80.8 x 110.0 mm, 103 parts (0 on the bottom side), 70 nets.

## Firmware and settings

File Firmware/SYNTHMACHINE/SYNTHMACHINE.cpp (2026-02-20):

/** MIDI Handling based on USB Midi example */
/** Code designed for MCP4728 4 channel 12-bit I2C DAC */
#include "daisy_seed.h"
#include "usbh_midi.h"
#include "daisysp.h"

using namespace daisy;
using namespace daisysp;

DaisySeed      hw;
MidiUsbHandler midi;
USBHostHandle  usbHost;

#define BUFF_SIZE 12
static uint8_t DMA_BUFFER_MEM_SECTION DAC_output_buffer[BUFF_SIZE];

#define MIDI_MAX 75
#define MIDI_MIN 28
#define I2C_SAMPLE_RATE 3000

class CustomAdsr { //State machine for handling envelopes, sits in release state unless note on
    public:
        enum EnvState { //enum for tracking current phase of ADSR envelope
            Attack,
            Decay,
            Sustain,
            Release
        };

        enum NoteState {
            OnNote,
            OffNote
        };

        EnvState Env_State = Release;
        NoteState Note_Stat = OffNote;

        float sample_rate;

        float AttackTime; //set in seconds
        float DecayTime;
        float ReleaseTime;
        float SustainPoint;

        float ADSR_Sample_Val = 0;
        float ADSR_Sample_Val_old = 0;

        void ProcessEnvNoteOn (){ //computes next sample of envelope based on current state and previous sample value, switches where appropriate
            
            switch(Env_State) {
                case Attack:
                    if (ADSR_Sample_Val >= 1){
                        ADSR_Sample_Val = 1;
                        Env_State = Decay;
                    } else {
                        ADSR_Sample_Val += 1 / (sample_rate*AttackTime);
                    }
                break;
                
                case Decay:
                    if (ADSR_Sample_Val <= SustainPoint){
                        ADSR_Sample_Val = SustainPoint;
                        Env_State = Sustain;
                    } else {
                        ADSR_Sample_Val -= (1-SustainPoint) / (sample_rate*DecayTime);
                    }
                break;

                case Sustain:
                    ADSR_Sample_Val = SustainPoint;
                break;

                case Release:
                    Env_State = Attack;
                    ADSR_Sample_Val = 0;
                break;
            }
            if (ADSR_Sample_Val >= 1){
                ADSR_Sample_Val = 1;
            }
            if (ADSR_Sample_Val <= 0){
                ADSR_Sample_Val = 0;
            }

        }

        void ProcessEnvNoteOff (){ //handles transitioning to release state and computing samples for release portion of envelope
                
                switch(Env_State) {
                    case Attack:
                        if (ADSR_Sample_Val >= 1){
                            ADSR_Sample_Val = 1;
                        }
                        ADSR_Sample_Val_old = ADSR_Sample_Val;
                        Env_State = Release;
                    break;
                    
                    case Decay:
                        ADSR_Sample_Val_old = ADSR_Sample_Val;
                        Env_State = Release;
                    break;

                    case Sustain:
                        ADSR_Sample_Val_old = ADSR_Sample_Val;
                        Env_State = Release;
                    break;

                    case Release:
                        ADSR_Sample_Val -= ADSR_Sample_Val_old / (sample_rate * ReleaseTime);
                    break;
                }

                if (ADSR_Sample_Val <= 0){
                    ADSR_Sample_Val = 0;
                }

            }

        void ProcessENV(){ //computes next sample to send to CV each time it is called
            switch(Note_Stat){
                case OnNote:
                    ProcessEnvNoteOn();
                    break;
                case OffNote:
                    ProcessEnvNoteOff();
                    break; 
            }
        }

        void SetState(NoteState Note_State_Ext){
            Note_Stat = Note_State_Ext;
        }

        CustomAdsr(float Sample_Rate_Ext, float AttackTime_Ext, float DecayTime_Ext, float SustainPoint_Ext, float ReleaseTime_Ext){
            AttackTime = AttackTime_Ext;
            DecayTime = DecayTime_Ext;
            SustainPoint = SustainPoint_Ext;
            ReleaseTime = ReleaseTime_Ext;
            sample_rate = Sample_Rate_Ext;
        }
};

/** FIFO to hold messages as we're ready to print them - holdover from example code*/
FIFO<MidiEvent, 128> event_log;

void USBH_Connect(void* data)
{
    //hw.PrintLine("device connected");
}

void USBH_Disconnect(void* data)
{
    //hw.PrintLine("device disconnected");
}

void USBH_ClassActive(void* data)
{
    if(usbHost.IsActiveClass(USBH_MIDI_CLASS))
    {
        //hw.PrintLine("MIDI device class active");
        MidiUsbHandler::Config midi_config;
        midi_config.transport_config.periph = MidiUsbTransport::Config::Periph::HOST;
        midi.Init(midi_config);
        midi.StartReceive();
    }
}

void USBH_Error(void* data)
{
    //hw.PrintLine("USB device error");
}

uint8_t DAC_I2C_GENERATE_MULTI_CHANNEL_PARAMS(uint8_t VREF, uint8_t PD1, uint8_t PD0, uint8_t Gx){
    //generates channel top bits for multi-write, see SET VREF and SET GAIN and MULTI_WRITE, PD1 and PD0 should be set 0 with current hardware configuration
    uint8_t top_bits = ((VREF << 7) | (PD1 << 6) | (PD0 << 5) | (Gx << 4));
    return top_bits;
}

void DAC_I2C_MULTI_WRITE(uint8_t DAC_Address, uint8_t* DAC_top_bits, uint16_t* channels, uint8_t* output_buffer, uint8_t UDAC, I2CHandle I2C) { 
    //writes all DACS at once, channels stores output values, DAC_top_bits stores per-channel vref, gain, and power down
    for (uint8_t i = 0; i < 4; i++){
        if (channels[i] > 0xFFF){
            channels[i] = 0xFFF;
        }
        output_buffer[3*i] = static_cast<uint8_t>(0x40 | (i << 1) | UDAC);
        output_buffer[3*i+1] = static_cast<uint8_t>(DAC_top_bits[i] | channels[i] >> 8);
        output_buffer[3*i + 2] = static_cast<uint8_t>(channels[i] & 0xFF);
    }

    I2CHandle::Result Multi_Write_Result = I2C.TransmitDma(DAC_Address, &output_buffer[0], 12, NULL, NULL);
    if(Multi_Write_Result == I2CHandle::Result::OK) {
        //hw.PrintLine("OK TRANSMISSION Multi Write");
    }
}

void DAC_I2C_SET_VREF(uint8_t DAC_Address, uint8_t V_A, uint8_t V_B, uint8_t V_C, uint8_t V_D, uint8_t* output_buffer, I2CHandle I2C){
    //sets reference voltage for each channel, use at startup only, 0 = VDD, 1 = Internal Reference (2.048V)
    output_buffer[0] = (0x80 | (V_A << 3) | (V_B << 2) | (V_C << 1) | V_D); // command (4bits) Vref A Vref B Vref C Vref D
    I2CHandle::Result Vref_Write_Result = I2C.TransmitDma(DAC_Address, &output_buffer[0], 1, NULL, NULL);
    if(Vref_Write_Result == I2CHandle::Result::OK) {
        //hw.PrintLine("OK TRANSMISSION VREF Write");
    }
}

void DAC_I2C_SET_GAIN(uint8_t DAC_Address, uint8_t G_A, uint8_t G_B, uint8_t G_C, uint8_t G_D, uint8_t* output_buffer, I2CHandle I2C){
    //sets gain for each channel, use at startup only, 0 = gain of 1 (0-2.048 V if Vref internal), 1 = gain of 2 (0 - 4.096 V if Vref internal), if Vref = VDD set to 0
    output_buffer[0] = (0xC0 | (G_A << 3) | (G_B << 2) | (G_C << 1) | G_D); // command (4bits) Gx A Gx B Gx C Gx D
    I2CHandle::Result Gain_Write_Result = I2C.TransmitDma(DAC_Address, &output_buffer[0], 1, NULL, NULL);
    if(Gain_Write_Result == I2CHandle::Result::OK) {
        //hw.PrintLine("OK TRANSMISSION GAIN Write");
    }
}

uint16_t MIDI_NOTE_TO_DAC_VOLTAGE(uint8_t note){ //Converts input midi note to 12bit int for CV DAC
    uint16_t MIDI_Range = MIDI_MAX - MIDI_MIN; 
    uint16_t DAC_Range = 4095;
    uint16_t DAC_Channel_Val = ((static_cast<uint16_t>(note) - MIDI_MIN) * DAC_Range) / MIDI_Range;

    return DAC_Channel_Val;
}

uint16_t OSC_AMP_TO_DAC_VOLTAGE(float value){ //unused function for osc
    float OSC_RANGE = 1.0f - (-1.0f); 
    float DAC_Range = 4095;
    float DAC_Channel_Val = ((value - (-1.0f)) * DAC_Range) / OSC_RANGE;

    return static_cast<uint16_t>(DAC_Channel_Val);
}

uint16_t Env_AMP_TO_DAC_VOLTAGE(float value){ //converts envelope amplitude range (ranging from 0 - 1) to 12-bit int value for envelope DAC
    float Env_RANGE = 1.0f; 
    float DAC_Range = 4095;
    float DAC_Channel_Val = ((value) * DAC_Range) / Env_RANGE;

    return static_cast<uint16_t>(DAC_Channel_Val);
}

int main(void)
{
    /** Initialize our hardware */
    hw.Init();
    //hw.StartLog(true);

    //initialize Timer stuff
    TimerHandle timer;
    TimerHandle::Config T_CONFIG;
    T_CONFIG.dir = TimerHandle::Config::CounterDir::UP;
    T_CONFIG.periph = TimerHandle::Config::Peripheral::TIM_2;
    timer.Init(T_CONFIG);
    timer.Start();

    uint32_t freq = timer.GetFreq();
    uint32_t lastTime = timer.GetTick();
    float interval = 0;

    //hw.StartLog(true);

    //hw.PrintLine("MIDI USB Host start");

    /** Configure USB host */
    USBHostHandle::Config usbhConfig;
    usbhConfig.connect_callback = USBH_Connect;
    usbhConfig.disconnect_callback = USBH_Disconnect;
    usbhConfig.class_active_callback = USBH_ClassActive;
    usbhConfig.error_callback = USBH_Error;
    usbHost.Init(usbhConfig);

    usbHost.RegisterClass(USBH_MIDI_CLASS);

    float now      = 0;
    float log_time = 0;
    float blink_time = 0;
    bool ledState = false;
    float I2C_Signal_Clock = 0; //holds current value of clock, used specifically for timing DAC samples
    uint8_t LED_INTER = 50;

    //hw.PrintLine("MIDI USB Host initialized");

    //configure the peripheral
    I2CHandle::Config _i2c_config;
    _i2c_config.periph = I2CHandle::Config::Peripheral::I2C_1;
    _i2c_config.speed  = I2CHandle::Config::Speed::I2C_400KHZ;
    _i2c_config.mode   = I2CHandle::Config::Mode::I2C_MASTER;
    _i2c_config.pin_config.scl  = seed::D11;
    _i2c_config.pin_config.sda  = seed::D12;
    // Address not needed for controller!

    // initialise the peripheral
    I2CHandle _i2c;
    _i2c.Init(_i2c_config);

    DAC_I2C_SET_VREF(0x60, 1, 1, 1, 1, &DAC_output_buffer[0], _i2c);
    DAC_I2C_SET_GAIN(0x60, 0, 0, 0, 0, &DAC_output_buffer[0], _i2c);

    uint16_t DAC_Channels[4] = {4095,3071,2047,1023};
        uint8_t DAC_Multi_Channel_Params[4] = {0,0,0,0};

        for (uint8_t i = 0; i < 4; i++){
            DAC_Multi_Channel_Params[i] = DAC_I2C_GENERATE_MULTI_CHANNEL_PARAMS(1,0,0,0);
        }

    /** initialize sine wave osc used to test DAC, outdated
    Oscillator sine_osc;
    sine_osc.Init(I2C_SAMPLE_RATE);
    sine_osc.SetFreq(100);
    sine_osc.SetWaveform(sine_osc.WAVE_SIN);
    sine_osc.SetAmp(1.0f);
    
    float sample = 0;
    */
    
    //initialize envelope
    CustomAdsr VolumeEnv(I2C_SAMPLE_RATE,0.1,0.1,0.5,0.1);

    /** Infinite Loop */
    while(1)
    {
        uint32_t newTick = timer.GetTick();
        interval = ((float)(newTick - lastTime) / (float)freq);
        lastTime = newTick;

        now += interval;
        blink_time += 1000.0 * interval;
        I2C_Signal_Clock += interval;

//Run USB host process
        usbHost.Process();

        if(usbHost.IsActiveClass(USBH_MIDI_CLASS) && midi.RxActive())
        {
            //Process MIDI in the background
            midi.Listen();

            //Loop through any MIDI Events
            while(midi.HasEvents())
            {
                MidiEvent msg = midi.PopEvent();

                //Handle messages as they come in 
                //See DaisyExamples for some examples of this
                
                switch(msg.type)
                {
                    case NoteOn:
                        // Do something on Note On events
                        {
                            //uint8_t VelID = msg.AsNoteOn().velocity;
                            DAC_Channels[0] = MIDI_NOTE_TO_DAC_VOLTAGE(msg.AsNoteOn().note); //sets the value to be sent to note CV based on current midi note
                            VolumeEnv.SetState(CustomAdsr::OnNote);
                        }
                        break;

                    case NoteOff:
                    {
                        VolumeEnv.SetState(CustomAdsr::OffNote);
                    }
                    default: break;
                }

                //Regardless of message, let's add the message data to our queue to output
                event_log.PushBack(msg);
            }

        }
        
        if(I2C_Signal_Clock >= (1.0f / I2C_SAMPLE_RATE)){
            I2C_Signal_Clock = 0;
            VolumeEnv.ProcessENV();

            DAC_Channels[2] = Env_AMP_TO_DAC_VOLTAGE(VolumeEnv.ADSR_Sample_Val);
            //hw.PrintLine("%d %d", OSC_AMP_TO_DAC_VOLTAGE(sample),static_cast<uint16_t>((sample+1)*10));
            DAC_I2C_MULTI_WRITE(0x60,DAC_Multi_Channel_Params,DAC_Channels,DAC_output_buffer,1,_i2c);
        }

        if (blink_time > LED_INTER)
        {
            blink_time = 0;
            hw.SetLed(ledState);
            ledState = !ledState;
            if (usbHost.GetPresent())
                LED_INTER = 50;
            else
                LED_INTER = 25;
        }

    }
}

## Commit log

2026-02-12 Added Initial KiCAD files
    [SynthMachine.kicad_pcb, SynthMachine.kicad_sch]
2026-02-12 deleted: SynthMachine.kicad_pcb deleted: SynthMachine.kicad_pro deleted: SynthMachine.kicad_sch
    [SynthMachine.kicad_pcb, SynthMachine.kicad_sch]
2026-02-12 new file: Hardware/Basic_VCO/Basic_VCO/Basic_VCO.kicad_pcb new file: Hardware/Basic_VCO/Basic_VCO/Basic_VCO.kicad_pro new file: Hardware/Basic_VCO/Basic_VCO/Basic_VCO.kicad_sch
    [Basic_VCO.kicad_pcb, Basic_VCO.kicad_sch]
2026-02-12 renamed: Hardware/Basic_VCO/Basic_VCO/Basic_VCO.kicad_pcb -> Hardware/Basic_VCO/Basic_VCO.kicad_pcb new file: Hardware/Basic_VCO/Basic_VCO.kicad_pro renamed: Hardware/Basic_VCO/Basic_VCO/Basic_VCO.ki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
    [Basic_VCO.kicad_pcb, Basic_VCO.kicad_sch]
2026-02-12 Initial Design Work - Test
    [Basic_VCO.kicad_sch]
2026-02-13 modified: Hardware/Basic_VCO/Basic_VCO.kicad_sch
    [Basic_VCO.kicad_sch]
2026-02-20 Added Daisy Seed Firmware, currently just here for reference, need to fix build environment.
    [SYNTHMACHINE.cpp]
2026-02-20 Updated Basic VCO schematic, still missing inputs, and mixer controls.
    [Basic_VCO.kicad_sch]
2026-02-20 Added Initial Schematic for controller board using daisy seed for midi to cv and envelope controls
    [Basic_VCO.kicad_sch, Controller_Board.kicad_pcb, Controller_Board.kicad_sch]
2026-02-26 Additional work to VCO schematic
    [Basic_VCO.kicad_sch]
2026-02-28 Finished 1st revision schematic for Basic VCO
    [Basic_VCO.kicad_sch]
2026-02-28 set some pcb footprints
    [Basic_VCO.kicad_sch]
2026-02-28 Changed Crossfade CV input to have 5V when disconnected instead of ground.
    Previously the Crossfade CV input would be grounded when disconnected from a CV source. now it is 5V allowing it to be set statically using offset and magnitude. CV input was designed expecting 10Vp-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
    [Basic_VCO.kicad_sch]
2026-03-04 adjusted schematic and prepared footprints for pcb design
    [Basic_VCO.kicad_pcb, Basic_VCO.kicad_sch]
2026-03-08 Re-organized, Basic VCO is now VCO MACHINE.
    Completed first version of PCBs, Basic VCO has been renamed to VCO MACHINE and redesigned to be split across two PCBs, connected via IDC, with Molex KK connectors for panel mount components.
    [B1.kicad_sch, B2.kicad_sch, Basic_VCO.kicad_pcb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]
